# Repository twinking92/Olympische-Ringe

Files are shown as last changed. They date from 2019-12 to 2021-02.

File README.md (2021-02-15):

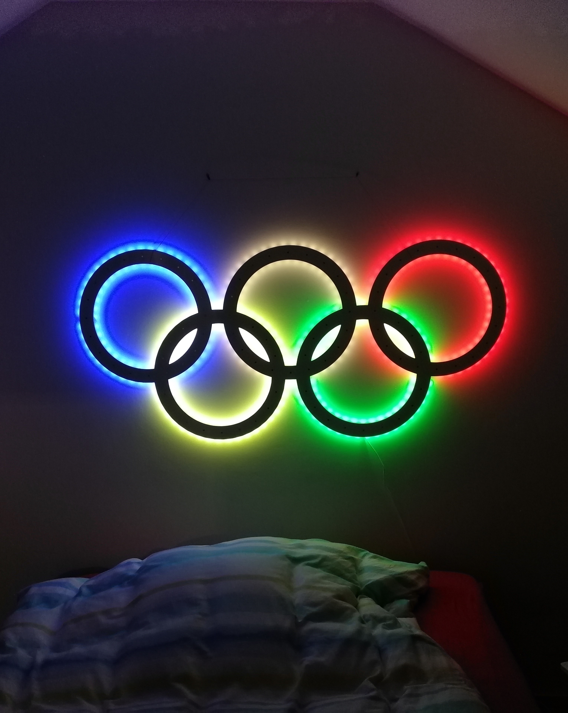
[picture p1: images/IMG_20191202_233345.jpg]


# Olympische Ringe RGBW Lampe

  

### Eine Open-Source RGB Lampe in Form der Olympischen Ringe als DIY Projekt
### Designed by Fabian Spinrath ([@twinking92](https://github.com/twinking92))

Die olympischen Ringe bestehen aus acht Segmenten welche aus 3mm und 12mm starken MDF-Platten gefräst und anschließend zusammen "gepuzzelt" werden. In der Oberfläche der Ringe sind 86 Magnete eingelassen, sodass die Lampe auch als Pinnwand genutzt werden kann.
Die Beleuchtung basiert auf individuell adressierbaren RGBW LED-Streifen des Typs SK6812 welche von einem ESP32 bzw. einem ESP8266 angesteuert werden. Über einen Induktiven Taster unter der Oberfläche der Ringe kann die Lampe angeschalten werden. Es gibt zwei Einschalttypen und Animationen:

- Fade On / Fade Off für weißes Licht (einfacher Klick)
- Step On / Step Off für Licht in den Farben der olympischen Ringe (Doppelklick)

Mit einem langen Klick kann die Helligkeit in fünf Stufen durchgeschalten werden.

Die Animationen werden non-blocking ausgeführt. Daher wäre es möglich einen Server auf dem ESP einzurichten und die Lampe fernzusteuern. Dies ist jedoch noch nicht implementiert.

Das 5V 10A Netzteil von Meanwell wird in einem ebenfalls gefrästen Gehäuse aus 4mm starken Multiplex-Platten untergebracht.

<details>
<summary>

# Mehr Bilder
</summary>

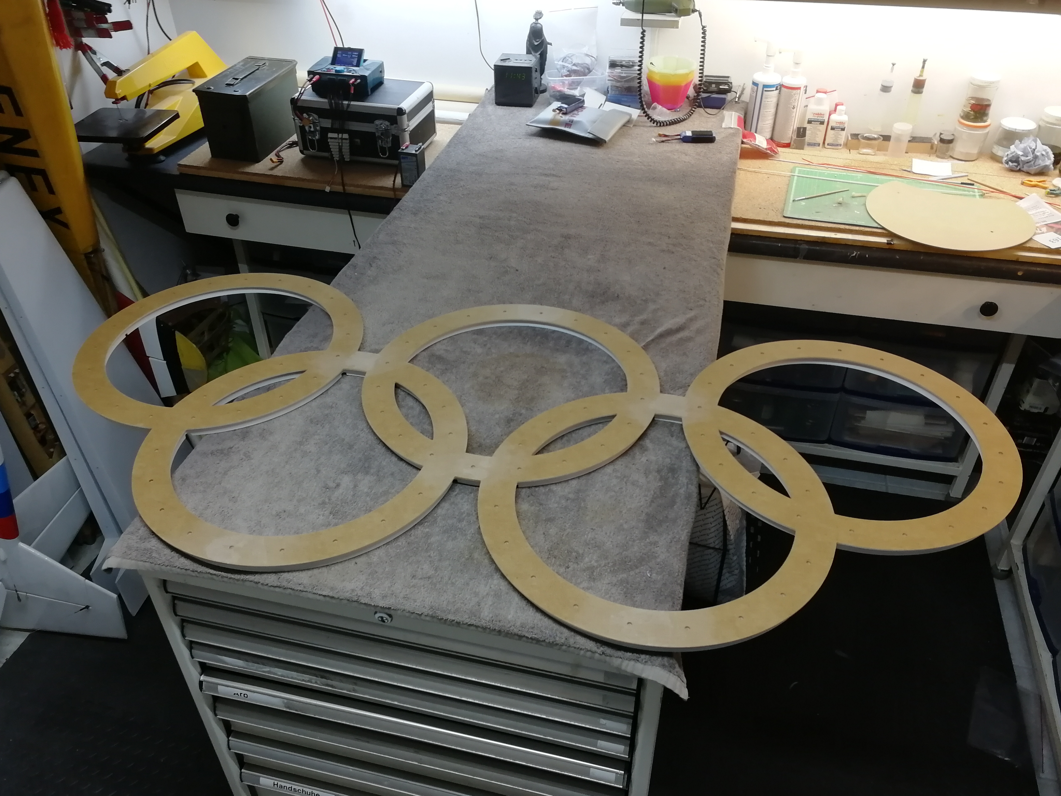
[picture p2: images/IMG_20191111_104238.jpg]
  |  |  
 -----------------------------|---------------------------|------------------------
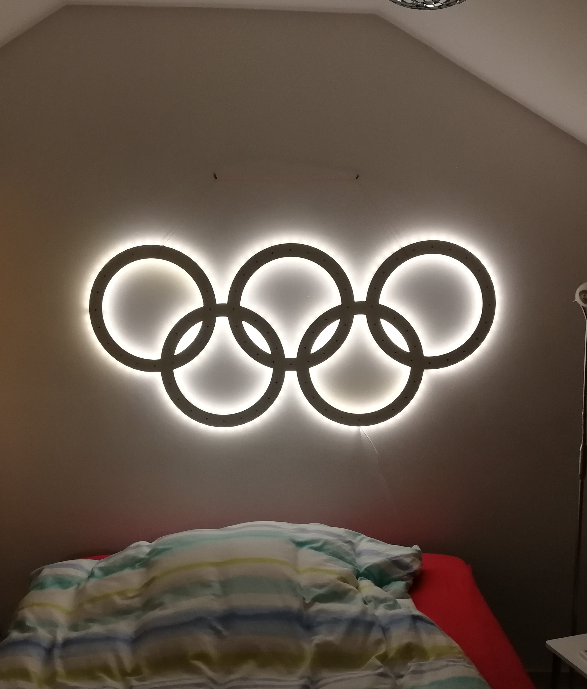
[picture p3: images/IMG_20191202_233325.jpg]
  |  |  
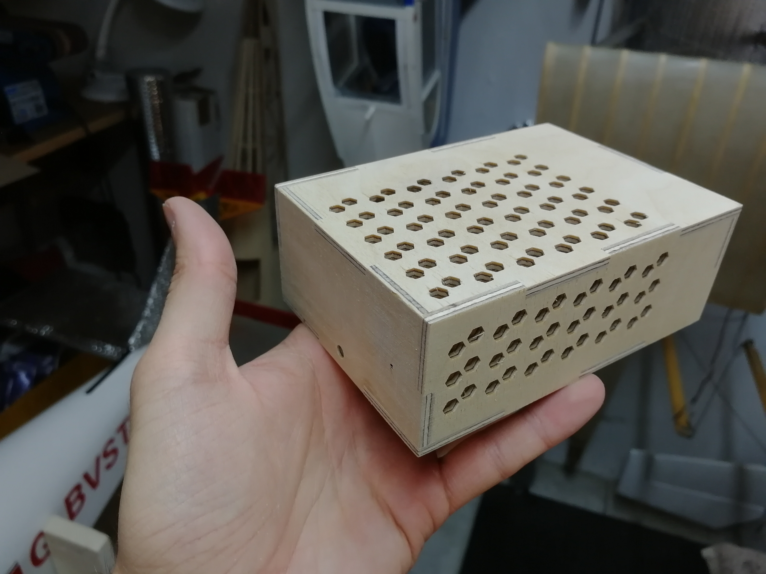
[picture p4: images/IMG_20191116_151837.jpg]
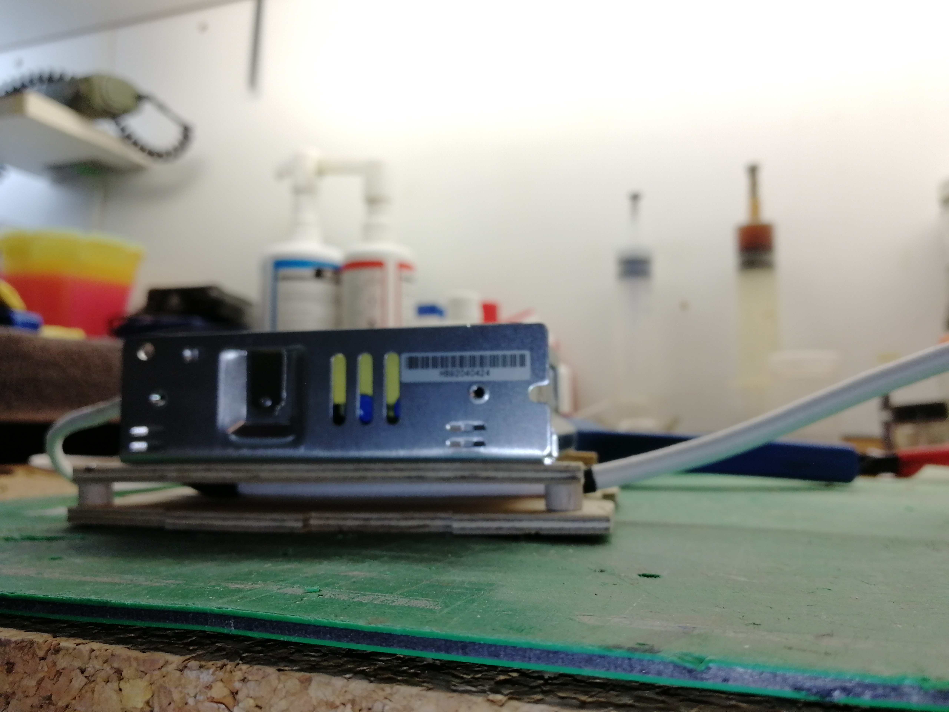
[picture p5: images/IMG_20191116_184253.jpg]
  |  |  
  |  |  
 
 </details>

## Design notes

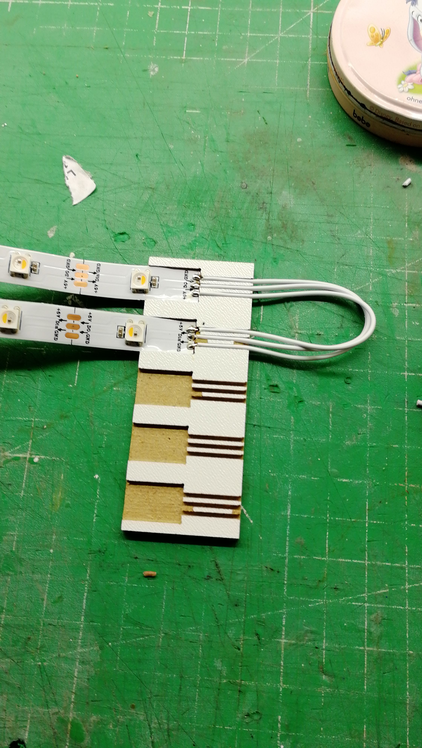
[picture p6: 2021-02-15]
images/IMG-20191129-WA0011.jpeg

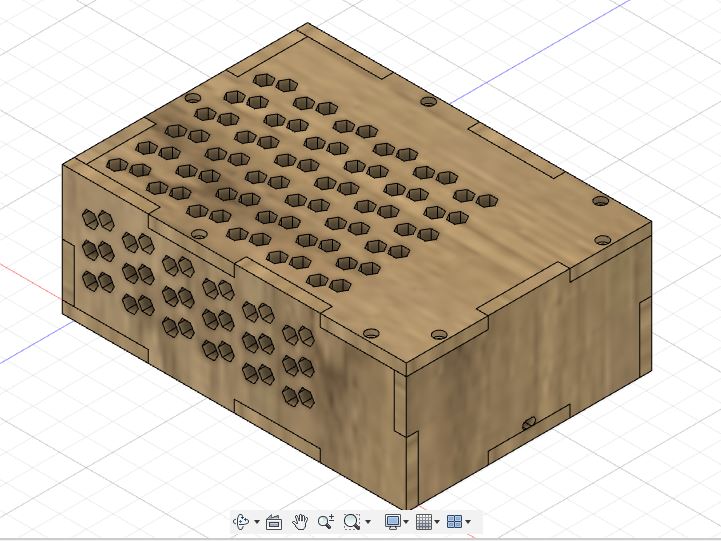
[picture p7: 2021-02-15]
dxfs/Netzteil/CAD in Fusion.JPG

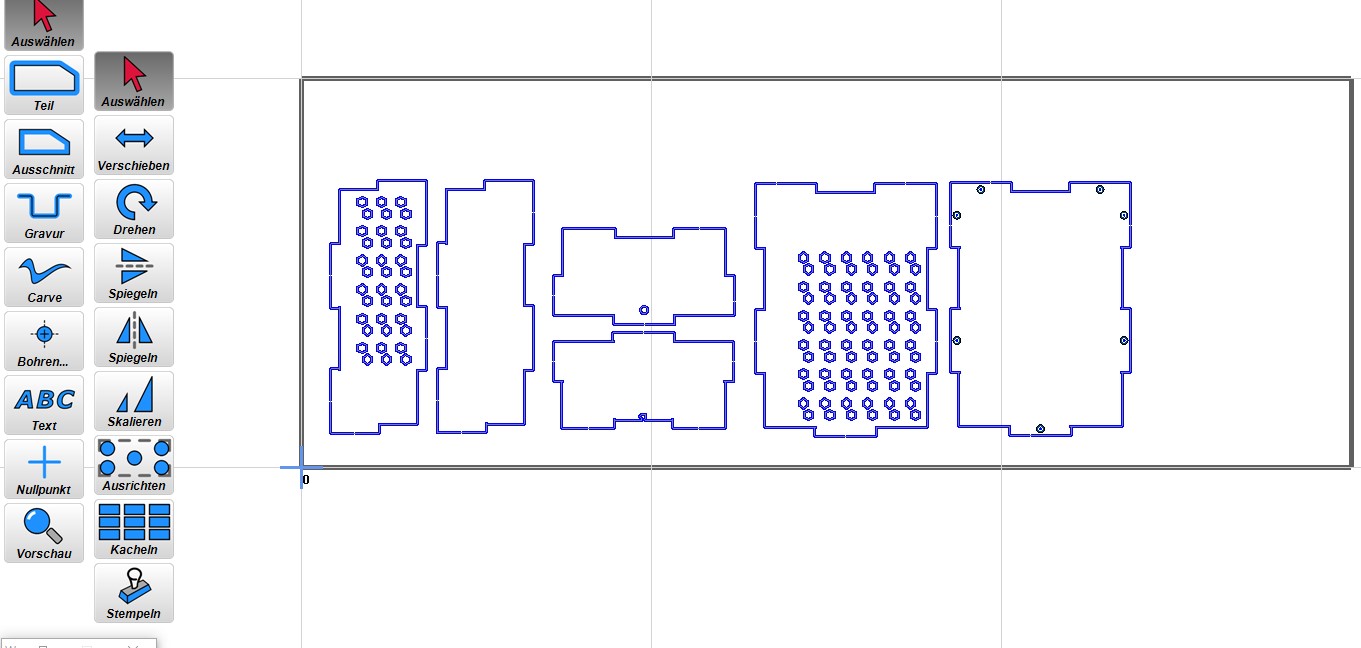
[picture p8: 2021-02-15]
dxfs/Netzteil/CAM in Estlcam.jpg

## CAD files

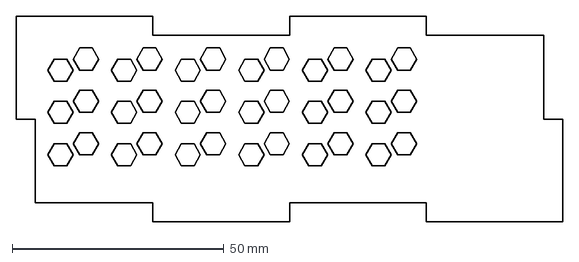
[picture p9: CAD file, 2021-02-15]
dxfs/Netzteil/Lange Seite fertigen.dxf
129.0 x 48.5 mm

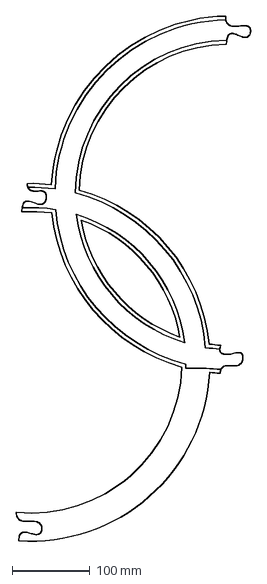
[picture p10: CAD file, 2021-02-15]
dxfs/Rückwand 2.dxf
300.7 x 677.8 mm

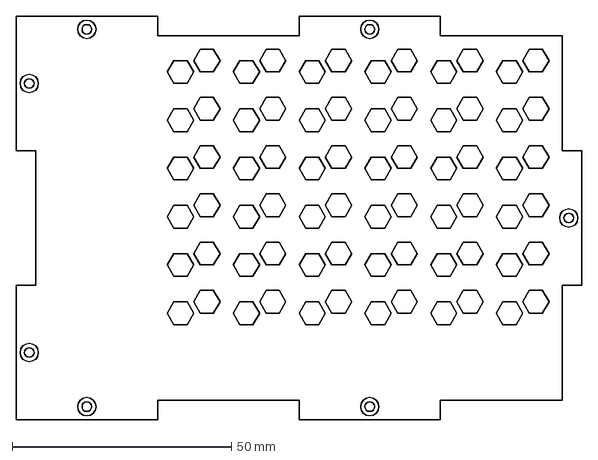
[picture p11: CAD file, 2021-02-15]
dxfs/Netzteil/Deckel fertigen.dxf
129.0 x 92.0 mm

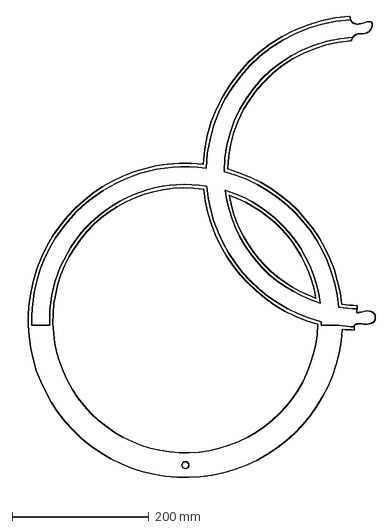
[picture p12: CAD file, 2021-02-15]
dxfs/Rückwand 4.dxf
524.5 x 691.6 mm

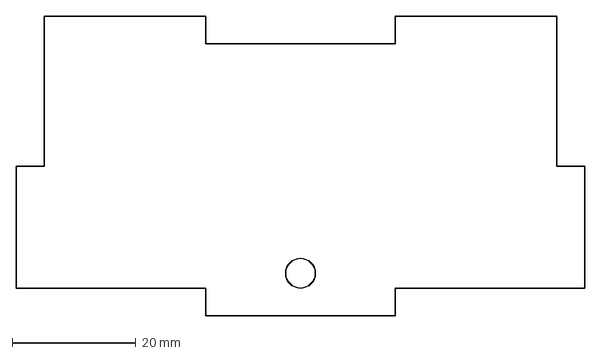
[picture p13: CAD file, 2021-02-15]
dxfs/Netzteil/Kurze Seite AC fertigen.dxf
92.0 x 48.5 mm

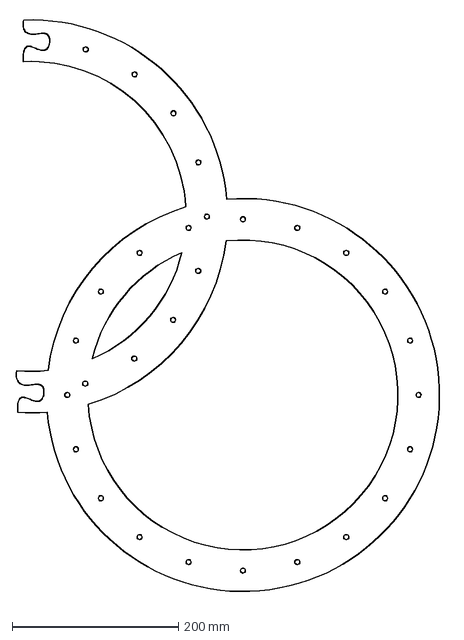
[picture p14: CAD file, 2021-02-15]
dxfs/Ring Segment 1.dxf
519.7 x 703.1 mm

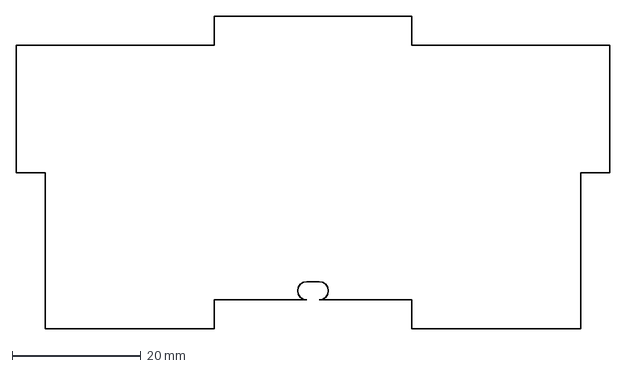
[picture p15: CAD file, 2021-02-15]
dxfs/Netzteil/Kurze Seite DC fertigen.dxf
92.0 x 48.5 mm

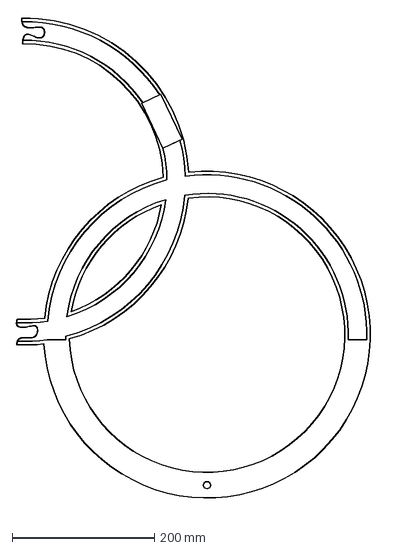
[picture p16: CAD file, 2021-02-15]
dxfs/Rückwand 1.dxf
514.6 x 694.9 mm

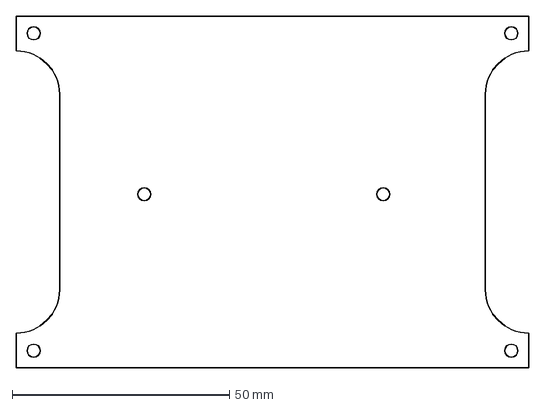
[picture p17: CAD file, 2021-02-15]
dxfs/Netzteil/Träger fertigen.dxf
118.0 x 81.0 mm

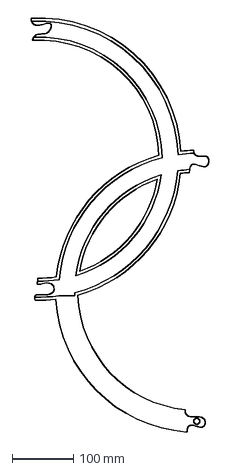
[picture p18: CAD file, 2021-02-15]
dxfs/Rückwand 3.dxf
289.2 x 677.0 mm

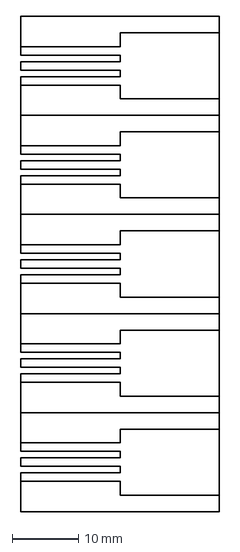
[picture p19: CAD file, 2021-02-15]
dxfs/Löthilfe.dxf
30.0 x 75.0 mm

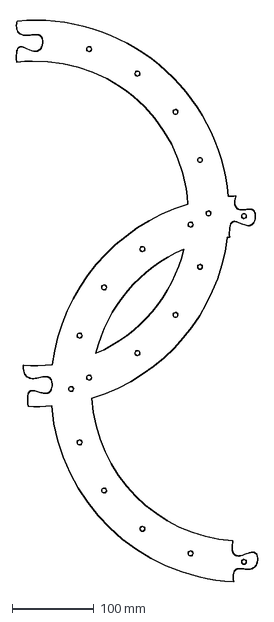
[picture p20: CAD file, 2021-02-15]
dxfs/Ring Segment 3.dxf
295.7 x 692.8 mm

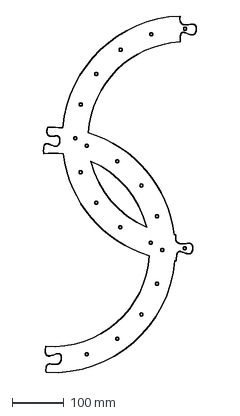
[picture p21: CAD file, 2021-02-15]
dxfs/Ring Segment 2.dxf
295.4 x 694.5 mm

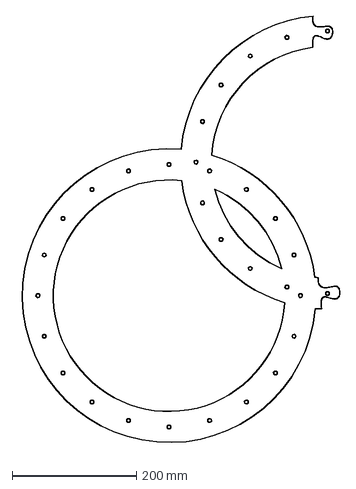
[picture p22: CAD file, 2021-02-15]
dxfs/Ring Segment 4.dxf
521.9 x 697.3 mm

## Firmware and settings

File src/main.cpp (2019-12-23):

#include <Arduino.h>
#include <WS2812FX.h>
#include "Button.h"
#ifdef ESP32
  #include "ESP32_RMT_Driver.h"
#endif

#define NUMBER_OF_LEDS 339
#define LED_START_BRIGHTNESS 51
#define LED_PIN D5
#define BUTTON_PIN D8
#define FADE_ON_TIME 2000
#define FADE_OFF_TIME 500
#define STEP_ON_TIME 2000
#define STEP_OFF_TIME 500
#define ANIMATION_ON_STARTUP 0 // 0: keine 1: fade on 2: step on

#define YELLOW (uint32_t)0xFF6000
#define DARKWHITE (uint32_t)0x11000000

bool stepOn(int channel, int startBit, int stopBit, long color, int time, bool onOff);
bool fadeOn(int channel, int startBit, int stopBit, long color, int time, bool onOff);
void showLEDsInFrames(unsigned int frames);
#ifdef ESP32
  void myCustomShow1(void);
#endif

WS2812FX leds = WS2812FX(NUMBER_OF_LEDS, LED_PIN, NEO_GRBW + NEO_KHZ800);
Button button(BUTTON_PIN);

bool animationRunning = false;
int animationMode = -1;
int clickStatus = ANIMATION_ON_STARTUP;
unsigned long startOfAnimationTime = 0;

void setup() {
  // Start Serial Connection
  Serial.begin(115200);
  delay(100);
  Serial.println("\nWillkommen zu den Olympischen Spielen");

  // LEDs initialisieren
  leds.init();
  #ifdef ESP32
    rmt_tx_int(RMT_CHANNEL_0, leds.getPin());
    leds.setCustomShow(myCustomShow1); 
  #endif
  leds.setBrightness(LED_START_BRIGHTNESS);
  leds.start();
}

void loop() {
  // Aktualisiere LEDs
  showLEDsInFrames(35);

  // Verarbeite Eingabe
  switch (clickStatus){
    case 0:
      break; // tue nichts
    case 1:
      if ( animationRunning || ( animationMode > 0)){ // Wenn Annimation läuft und Lampe eingeschalten ist
        animationMode = -animationMode;               // -> Animation umkehren
        Serial.println("<--- Off");  
      } else if ( animationMode < 0 ){                // sonst wenn Lampe aus
        animationMode = 1;                            // -> Schalte Lampe mit Mode 1 an
        Serial.println("---> Fade On"); 
      }
      animationRunning = true;
      startOfAnimationTime = millis(); // Debugging
      break;
    case 2:
      if ( animationRunning || ( animationMode > 0)){ // Wenn Annimation läuft und Lampe eingeschalten ist
        animationMode = -animationMode;               // -> Animation umkehren
        Serial.println("<---"); 
      } else if ( animationMode < 0 ){                // sonst wenn Lampe aus
        animationMode = 2;                            // -> Schalte Lampe mit Mode 2 an
        Serial.println("---> Step On"); 
      }
      animationRunning = true;
      startOfAnimationTime = millis(); // Debugging
      break;
    case 3:
      uint8_t tempBrightness = leds.getBrightness();
      tempBrightness += 51;
      if (tempBrightness < 51) tempBrightness = 51;
      leds.setBrightness(tempBrightness);
      Serial.printf("Helligkeit auf: %d\n", leds.getBrightness());
      break;
  }

  // Schalte Lampe abhängig vom geforderten Mode
  if (animationRunning){
    bool aR[10] = {true, true, true, true, true, true, true, true, true, true};
    switch (animationMode){
      case 1:
        aR[0] = fadeOn(0, 0, NUMBER_OF_LEDS, 0xFF000000, FADE_ON_TIME, true);
        //aR[0] = fadeOn(0, 0, NUMBER_OF_LEDS-1, WHITE, FADE_ON_TIME, true);
        break;
      case -1:
        aR[0] = fadeOn(0, 0, NUMBER_OF_LEDS, 0xFF000000, FADE_OFF_TIME, false); // RGBW
        //aR[0] = fadeOn(0, 0, NUMBER_OF_LEDS-1, WHITE, FADE_OFF_TIME, false);
        break;
      case 2:
        aR[0] = stepOn(0, 0, 39, RED, STEP_ON_TIME, true);
        aR[1] = stepOn(1, 40, 71, RED, STEP_ON_TIME, true);
        aR[2] = stepOn(2, 71, 108, GREEN, STEP_ON_TIME, true);
        aR[3] = stepOn(3, 109, 136, GREEN, STEP_ON_TIME, true);
        aR[4] = stepOn(4, 137, 173, DARKWHITE, STEP_ON_TIME, true);
        aR[5] = stepOn(5, 174, 201, DARKWHITE, STEP_ON_TIME, true);
        aR[6] = stepOn(6, 202, 238, YELLOW, STEP_ON_TIME, true);
        aR[7] = stepOn(7, 239, 266, YELLOW, STEP_ON_TIME, true);
        aR[8] = stepOn(8, 267, 306, BLUE, STEP_ON_TIME, true);
        aR[9] = stepOn(9, 307, 338, BLUE, STEP_ON_TIME, true);
        break;
      case -2:
        aR[0] = stepOn(0, 0, 39, RED, STEP_OFF_TIME, false);
        aR[1] = stepOn(1, 40, 71, RED, STEP_OFF_TIME, false);
        aR[2] = stepOn(2, 71, 108, GREEN, STEP_OFF_TIME, false);
        aR[3] = stepOn(3, 109, 136, GREEN, STEP_OFF_TIME, false);
        aR[4] = stepOn(4, 137, 173, DARKWHITE, STEP_OFF_TIME, false);
        aR[5] = stepOn(5, 174, 201, DARKWHITE, STEP_OFF_TIME, false);
        aR[6] = stepOn(6, 202, 238, YELLOW, STEP_OFF_TIME, false);
        aR[7] = stepOn(7, 239, 266, YELLOW, STEP_OFF_TIME, false);
        aR[8] = stepOn(8, 267, 306, BLUE, STEP_OFF_TIME, false);
        aR[9] = stepOn(9, 307, 338, BLUE, STEP_OFF_TIME, false);
        break;
    }
    if (aR[0] && aR[1] && aR[2] && aR[3] && aR[4] && aR[5] && aR[6] && aR[7] && aR[8] && aR[9]){  // Wenn alle Segmente true zurückgeben ist die Animation fertig
      animationRunning = false;
      Serial.printf("<%ldms>\n", millis()-startOfAnimationTime); // Debugging
    }
  }
  
  // Checke Eingabe
  clickStatus = button.ButtonLoop();
  if (Serial.available() > 0){ // Eingabe über Serial
    clickStatus = Serial.parseInt();
    Serial.println(clickStatus);
  }
}

bool stepOn(int channel, int startBit, int stopBit, long color, int time, bool onOff){
  bool animationStatus = false;
  static unsigned long lastMillis[10] = {};
  static int channelCounter[10] = {};
  unsigned int refreshTime = ((float)time/(stopBit-startBit)+0.5);
  if (onOff){
    if (channelCounter[channel] <= (stopBit - startBit)){      
      if ( (millis()-lastMillis[channel]) >= refreshTime ){
        leds.setPixelColor(startBit+channelCounter[channel], color);
        channelCounter[channel]++;          
        lastMillis[channel] = millis();
      }
    }else animationStatus = true;
  }else{
    if (channelCounter[channel] > 0 ){
      if ( (millis()-lastMillis[channel]) >= refreshTime ){
        leds.setPixelColor(startBit+channelCounter[channel]-1, BLACK);
        channelCounter[channel]--;          
        lastMillis[channel] = millis();
      }
    }else animationStatus = true;
  }
  return animationStatus;
}

bool fadeOn(int channel, int startBit, int stopBit, long color, int time, bool onOff){
  bool animationStatus = false;
  static unsigned lastMillis[10] = {};
  static int channelCounter[10] = {};
  unsigned int refreshTime = ((float)time/(255)+0.5);
  int r, g, b, w;
  w = color >> 24 & 0xFF; r = color >> 16 & 0xFF; g = color >> 8 & 0xFF; b = color & 0xFF;
  if (onOff){
    if (channelCounter[channel] <= 255){ 
      if ( (millis()-lastMillis[channel]) >= refreshTime) {
        leds.fill(leds.Color((float)r/255*(channelCounter[channel]), (float)g/255*(channelCounter[channel]), (float)b/255*(channelCounter[channel]), (float)w/255*(channelCounter[channel])), startBit, stopBit);
        channelCounter[channel]++;
        lastMillis[channel] = millis();
      }
    }else animationStatus = true;
  } else{
    if (channelCounter[channel] > 0 ){
      if ( (millis()-lastMillis[channel]) >= refreshTime) {
        leds.fill(leds.Color((float)r/255*(channelCounter[channel]-1), (float)g/255*(channelCounter[channel]-1), (float)b/255*(channelCounter[channel]-1), (float)w/255*(channelCounter[channel]-1)), startBit, stopBit);
        channelCounter[channel]--; 
        lastMillis[channel] = millis();
      }
    }else animationStatus = true;
  }
  return animationStatus;
}

void showLEDsInFrames(unsigned int frames){
  static unsigned long lastMillis = millis();
  if ( (millis()-lastMillis) >= (1000UL/frames) ){
    leds.show();
    lastMillis = millis();
  }
}

#ifdef ESP32
void myCustomShow1(void) {
  uint8_t *pixels = leds.getPixels();
  uint16_t numBytes = leds.getNumBytes() + 1;
  rmt_write_sample(RMT_CHANNEL_0, pixels, numBytes, false);
}
#endif

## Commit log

2019-11-25 Port to ESP8266 and change to Button Lib
2019-11-25 set pinMode in Button.cpp
2019-12-18 Yellow correction final birthday build
    [main.cpp]
2019-12-23 fixed fadeOn bug with non 255 colors
    [main.cpp]
2021-02-15 added dxfs
    [Deckel fertigen.dxf, Kurze Seite AC fertigen.dxf, Kurze Seite DC fertigen.dxf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]
